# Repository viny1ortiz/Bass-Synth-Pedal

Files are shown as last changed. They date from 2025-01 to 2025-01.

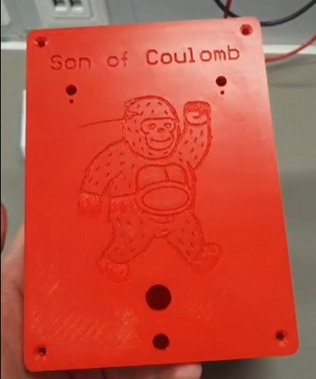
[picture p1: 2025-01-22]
3dprint/thumbnail.png

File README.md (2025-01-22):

# Son Of Coulomb - The Bass-Guitar Synthesizer Pedal

By: Vinicius Ourcilleon Ortiz and Gilberto Guerrero Carrillo  
**Rhine-Waal University of Applied Sciences**

A budget-friendly bass synthesizer pedal with square and triangle wave generation, designed and built for a university project. The objective of this project is to design and build a bass synthesizer pedal within a 20-euro budget. This budgetary constraint was not chosen out of necessity but as a deliberate design decision to limit the project's complexity and emphasize resourceful engineering.

The resulting pedal, named Son of Coulomb, processes the sinusoidal input signal from a bass guitar and offers several unique features. A dedicated switch allows the user to transform the input signal into either a triangular or square waveform. Another switch enables frequency multiplication, offering the option to shift the output one or two octaves higher (frequency multiplied by 2x or 4x).

The PCB design includes exposed pins for a microcontroller, allowing users to develop and upload custom effects. By connecting the microcontroller via jumpers, you can replace the default effect, which shifts the input signal one or two octaves up, with any custom effect of your choice through programming. This feature enhances the pedal's versatility and adaptability for creative experimentation.

Additionally, the pedal includes a 3PDT true bypass functionality, providing the user with seamless control to toggle between the unprocessed bass sound and the synthesized effect. This combination of simplicity, functionality, and cost-efficiency makes the Son of Coulomb an excellent showcase of analog signal processing and creative circuit design.

# How It Works: Flow Overview

To provide a clear understanding of the pedal's operation, the following workflow diagram outlines the core processes involved. This simple representation breaks down the system into distinct functional blocks, offering an intuitive overview of how the components interact. Below the diagram, each block is explained in detail to highlight its role within the system. Let’s explore each block step by step to understand how the Son of Coulomb transforms the input signal into the synthesized effect.



**Pre-Amplifier:** Before connecting the bass signal directly to the microcontroller, the signal must be amplified and offset to ensure compatibility with the microcontroller's input voltage range of 0 to 3.3V. Since the bass signal typically ranges between -100 mV and 100 mV, it is first offset to 1.65V (the midpoint of the microcontroller's input range) and then amplified to bring the signal within the acceptable voltage levels for accurate processing.

**MCU:** Within the microcontroller, the input signal is processed to extract its frequency. This frequency is then used to generate a PWM signal on two separate output pins, with the frequency scaled by a factor of 2 or 4, depending on the selected mode.

**SW1:** This switch simply selects whether the input frequency is multiplied by a factor of 2 or 4.

**Triangle Generator:** As the name suggests, the incoming signal from the microcontroller is converted from a square wave to a triangular wave using an integrator op-amp configuration.

**SW2:** This switch simply selects either a square or triangle wave, and its output goes directly to the effect output.

**Effect Bypass:** The effect bypass block, controlled by a 3PDT switch, determines whether the effect is active or bypassed. When the effect is enabled, the LED turns on, and the bass-guitar signal passes through the effect circuit. If the effect is bypassed, the signal is routed directly to the output jack, as depicted in the diagram.

**More details of the circuit can be seen in the "schematic" folder!**

# Demonstration

IMAGE ALT TEXT HERE (https://www.youtube.com/watch?v=soLUF7D458c)

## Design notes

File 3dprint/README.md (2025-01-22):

# Enclosure

This is the 3D CAD model of my enclosure, designed by my talented friend, mechanical engineer Vinod Seluam. It features four M4 screw threads and a reinforced structure to ensure durability, as the material will need to withstand foot pressure to activate the 3PDT foot-stomp switch. The printing process took approximately 12 hours. A big thank you to Vinod for his outstanding work on this design.




# Final Result

Watch "Pedal.mp4"!

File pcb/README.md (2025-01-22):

# Top Layer



# Bottom Layer



# Final Result



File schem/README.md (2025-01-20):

# Schematic

This schematic represents the complete design of the project. It outlines all key subcircuits that contribute to its functionality. We will now analyze each subcircuit in detail to understand their roles and operation.



# Power Supply


This is the power supply stage, designed to provide stable voltages for the circuit. The LM317 voltage regulator (IC1) is configured to generate a 3.3V output using resistors R7 and R1, with capacitor C3 providing additional stability. The input to the regulator is filtered by capacitor C5 to reduce noise. Additionally, a bias voltage is generated using a resistor divider network (R2 and R8), providing an offset of approximately 1.55V. This bias voltage is further stabilized by capacitor C4, ensuring a clean reference for subsequent stages in the circuit.

# Amplifier with Offset


This is the amplifier stage, primarily responsible for processing the signal before it is sent to the MCU. Resistor R17 provides high input impedance to preserve the signal integrity from the bass. The bias voltage, derived from the previously discussed power supply stage, offsets the signal by approximately 1.55V. The signal then passes through the voltage follower implemented with U1A and is subsequently amplified with a gain of approximately K=5.6 in U1B. The amplified output from U1B is connected directly to the MCU for further processing.

# MCU - STM32F103C8T6


This is the MCU stage, centered around the STM32F103C8T6 microcontroller, which handles signal processing and wave generation. The crystal oscillator (Y1) and its accompanying capacitors (C7 and C8) provide an 8 MHz clock for precise operation. The NRST pin is connected to a reset circuit, comprising a pull-up resistor (R3), a decoupling capacitor (C11), and a push-button (SW4) for manual resets.

For boot mode selection, the BOOT pin is configured using SW5 and pull-down resistor R15. The programming interface is accessible via J4, which connects the SWDIO and SWCLK lines for debugging and firmware uploads. Power stability is ensured with decoupling capacitors close to the MCU power pins, while pull-up resistor R4 supports proper initialization of the SWDIO line. Together, this stage forms the control hub of the system.

# Triangle Wave & Wave Selection


This is the triangle wave generator and wave selection stage. The input signal is chosen using the SPDT switch SW1, which selects between FX1 (2x frequency multiplier) and FX2 (4x frequency multiplier), sending the selected signal to the square wave output (SQR_OUT). The square wave is processed by a resistor-capacitor network (R5, R6, and C1), that basically removes the DC component of the signal so it can be fed into the integrator circuit implemented with U2A (LM358), which generates a triangle wave.

The SPDT switch SW2 allows selection between the square wave and triangle wave output. The chosen waveform is buffered by U2B, ensuring proper drive strength and signal integrity. The final output, labeled as 'Effect_out,' is conditioned by a resistor network (R9, R10) which decreases the amplitude of it to 10%, and decoupling capacitor C6 for stability and signal shaping. This stage provides the flexibility to toggle between waveforms.

# Effect Toggle - 3PDT


This is the toggling effect stage, which determines whether the signal bypasses the effect or passes through it. When the effect is activated, the LED illuminates, the input jack is connected to the effect input, and the effect output is routed to the output jack.

When toggled off, the LED turns off, the effect input is grounded to discharge any capacitors, and the input and output jacks are directly connected, bypassing the effect entirely and routing the signal straight to the amplifier.

# MCU Pin Headers


In this section, the MCU pins are directly routed to headers, enabling the use of the circuit as a versatile 'Pedal Effect' development board. This design allows users to create custom effects by programming the MCU and connecting the desired pins to the board for their specific effects. The SPDT switch (SW1) facilitates toggling between two effects, allowing up to two effects to be used simultaneously with seamless switching.

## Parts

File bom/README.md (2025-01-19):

The budget of this project was €20, however, we surpassed it a bit by €3.19

bom

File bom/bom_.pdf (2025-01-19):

Qty | Value | Description | Designator | Manufacturer | Manufacturer Part Number | Supplier | Supplier Part Number | Unit Cost | Cost
5 | 0.1u | Capacitor | C1, C3, C5, C10, C11 | Kyocera AVX | KAF21KR72A104KL | Mouser | 581-KAF21KR72A104KL | 0.16 € | 0.81 €
2 | 10u | Capacitor | C2, C6 | TDK | CGA3EDX7T1A106M080AU | Mouser | 810-CGA3EDX7T1A106M0 | 0.47 € | 0.93 €
1 | 47u | Capacitor | C4 | Nichicon | GXC1H470MCQ1GS | Mouser | 647-GXC1H470MCQ1GS | 1.11 € | 1.11 €
2 | 22p | Capacitor | C7, C8 | Kyocera AVX | 06036A220JAT2A | Mouser | 581-06036A220JAT2A | 0.10 € | 0.19 €
1 | 4.7u | Capacitor | C9 | Kyocera AVX | KAF21KR72A104KL | Mouser | 581-CM05X5R475M16AH | 0.21 € | 0.21 €
1 | Red LED | LED | DS1 | Cree LED | CMP-007-00007-2 | Mouser | 941-C566CRFECV0W0BB2 | 0.23 € | 0.23 €
1 | LM317DCY | IC | IC1 | Texas Instruments | LM317DCY | Mouser | 595-LM317DCY | 1.11 € | 1.11 €
1 | stm32f103c8t6 | MCU | IC2 | STMicroelectronics | stm32f103c8t6 | Reichelt | STM32 F103C8T6 | 1.60 € | 1.60 €
3 | Terminal Block - Jack in | Terminal Block | J1, J2, J3 | Same Sky | TB003-500-P02BE | Mouser | 490-TB003-500-P02BE | 0.46 € | 1.37 €
2 | 1.2k | Resistor | R1, R14 | Panasonic | ERJ-UP3F1201V | Mouser | 667-ERJ-UP3F1201V | 0.22 € | 0.44 €
4 | 47k | Resistor | R2, R6, R8, R11 | Panasonic | CR0603-JW-473ELF | Mouser | 652-CR0603-JW-473ELF | 0.10 € | 0.38 €
4 | 10k | Resistor | R3, R4, R9, R15 | ROHM Semiconductor | ESR03EZPJ103 | Mouser | 755-ESR03EZPJ103 | 0.11 € | 0.46 €
2 | 6.8k | Resistor | R5, R13 | Panasonic | ERJ-S03F6801V | Mouser | 667-ERJ-S03F6801V | 0.19 € | 0.38 €
1 | 1.8k | Resistor | R7 | Panasonic | ERA-6ARB182V | Mouser | 667-ERA-6ARB182V | 0.66 € | 0.66 €
2 | 1k | Resistor | R10, R16 | Panasonic | ERJ-P03F1001V | Mouser | 667-ERJ-P03F1001V | 0.16 € | 0.32 €
1 | 220 | Resistor | R12 | KOA Speer | RK73B1JTTDD221J | Mouser | 660-RK73B1JTTDD221J | 0.10 € | 0.10 €
2 | 1M | Resistor | R17, R18 | Vishay Draloric | RCV25121M00JNEG | Mouser | 71-RCV25121M00JNEG | 0.82 € | 1.63 €
2 | SPDT Switch | Switch | SW1, SW2 | Adafruit | 3221 | Mouser | 485-3221 | 0.90 € | 1.81 €
1 | 3PDT Switch | Switch | SW3 | E-Switch | FS57003PLT2B2M2QE | Mouser | 612-FS573PLT2B2M1QE | 7.59 € | 7.59 €
1 | Push Button (RESET) | Switch | SW4 | Apem | PHAP3344BR | Mouser | 642-PHAP3344BR | 0.42 € | 0.42 €
1 | Push Button (BOOT) | Switch | SW5 | Apem | PHAP3344BR | Mouser | 642-PHAP3344BR | 0.42 € | 0.42 €
2 | LM358DR | Dual Operational Amplifier | U1, U2 | Texas Instruments | LM358DR | Mouser | 595-LM358DR | 0.39 € | 0.78 €
1 | 8MHz | Crystal Oscillator | Y1 | Fox / Abracon | FOXSDLF_080-20 | Mouser | 559-FOXSD080-20-LF | 0.25 € | 0.25 €
| | | | | | | | Total Cost | 23.19 €

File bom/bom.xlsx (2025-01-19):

Qty |  | Value | Description | Designator | Manufacturer | Manufacturer Part Number | Supplier | Supplier Part Number | Unit Cost | Cost
5 | x | 0.1u | Capacitor | C1, C3, C5, C10, C11 | Kyocera AVX | KAF21KR72A104KL | Mouser | 581-KAF21KR72A104KL | 0.16 € | 0.81 €
2 | x | 10u | Capacitor | C2, C6 | TDK | CGA3EDX7T1A106M080AU | Mouser | 810-CGA3EDX7T1A106M0 | 0.47 € | 0.93 €
1 | x | 47u | Capacitor | C4 | Nichicon | GXC1H470MCQ1GS | Mouser | 647-GXC1H470MCQ1GS | 1.11 € | 1.11 €
2 | x | 22p | Capacitor | C7, C8 | Kyocera AVX | 06036A220JAT2A | Mouser | 581-06036A220JAT2A | 0.10 € | 0.19 €
1 | x | 4.7u | Capacitor | C9 | Kyocera AVX | KAF21KR72A104KL | Mouser | 581-CM05X5R475M16AH | 0.21 € | 0.21 €
1 |  | Red LED | LED | DS1 | Cree LED | CMP-007-00007-2 | Mouser | 941-C566CRFECV0W0BB2 | 0.23 € | 0.23 €
1 | x | LM317DCY | IC | IC1 | Texas Instruments | LM317DCY | Mouser | 595-LM317DCY | 1.11 € | 1.11 €
1 |  | stm32f103c8t6 | MCU | IC2 | STMicroelectronics | stm32f103c8t6 | Reichelt | STM32 F103C8T6 | 1.60 € | 1.60 €
3 |  | Terminal Block - Jack in | Terminal Block | J1, J2, J3 | Same Sky | TB003-500-P02BE | Mouser | 490-TB003-500-P02BE | 0.46 € | 1.37 €
2 | x | 1.2k | Resistor | R1, R14 | Panasonic | ERJ-UP3F1201V | Mouser | 667-ERJ-UP3F1201V | 0.22 € | 0.44 €
4 | x | 47k | Resistor | R2, R6, R8, R11 | Panasonic | CR0603-JW-473ELF | Mouser | 652-CR0603-JW-473ELF | 0.10 € | 0.38 €
4 | x | 10k | Resistor | R3, R4, R9, R15 | ROHM Semiconductor | ESR03EZPJ103 | Mouser | 755-ESR03EZPJ103 | 0.11 € | 0.46 €
2 | x | 6.8k | Resistor | R5, R13 | Panasonic | ERJ-S03F6801V | Mouser | 667-ERJ-S03F6801V | 0.19 € | 0.38 €
1 | x | 1.8k | Resistor | R7 | Panasonic | ERA-6ARB182V | Mouser | 667-ERA-6ARB182V | 0.66 € | 0.66 €
2 | x | 1k | Resistor | R10, R16 | Panasonic | ERJ-P03F1001V | Mouser | 667-ERJ-P03F1001V | 0.16 € | 0.32 €
1 | x | 220 | Resistor | R12 | KOA Speer | RK73B1JTTDD221J | Mouser | 660-RK73B1JTTDD221J | 0.10 € | 0.10 €
2 | x | 1M | Resistor | R17, R18 | Vishay Draloric | RCV25121M00JNEG | Mouser | 71-RCV25121M00JNEG | 0.82 € | 1.63 €
2 |  | SPDT Switch | Switch | SW1, SW2 | Adafruit | 3221 | Mouser | 485-3221 | 0.90 € | 1.81 €
1 |  | 3PDT Switch | Switch | SW3 | E-Switch | FS57003PLT2B2M2QE | Mouser | 612-FS573PLT2B2M1QE | 7.59 € | 7.59 €
1 |  | Push Button (RESET) | Switch | SW4 | Apem | PHAP3344BR | Mouser | 642-PHAP3344BR | 0.42 € | 0.42 €
1 |  | Push Button (BOOT) | Switch | SW5 | Apem | PHAP3344BR | Mouser | 642-PHAP3344BR | 0.42 € | 0.42 €
2 | x | LM358DR | Dual Operational Amplifier | U1, U2 | Texas Instruments | LM358DR | Mouser | 595-LM358DR | 0.39 € | 0.78 €
1 | x | 8MHz | Crystal Oscillator | Y1 | Fox / Abracon | FOXSDLF_080-20 | Mouser | 559-FOXSD080-20-LF | 0.25 € | 0.25 €
 |  |  |  |  |  |  |  |  | Total Cost | 23.19 €

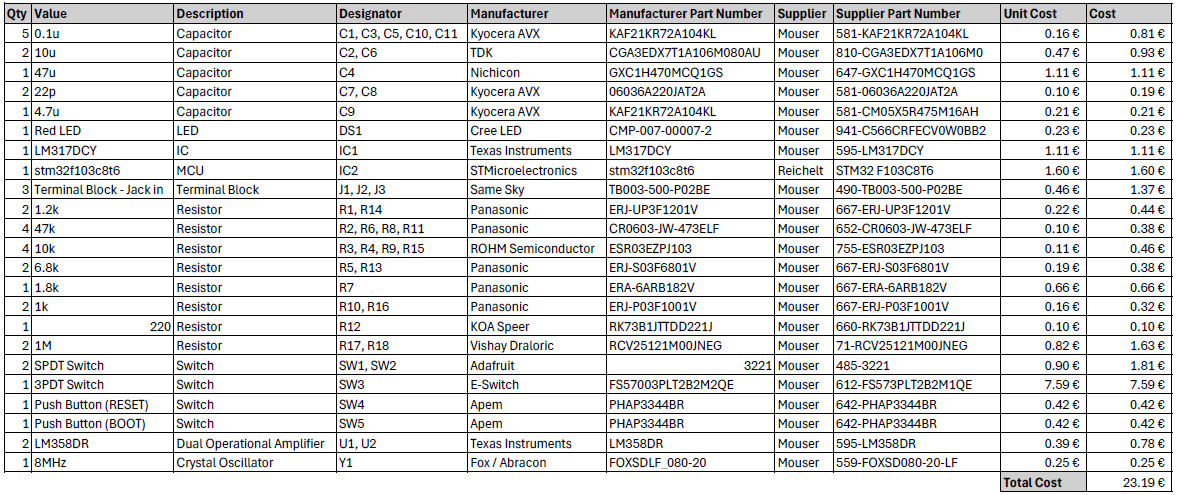
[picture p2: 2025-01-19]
bom/bom.png

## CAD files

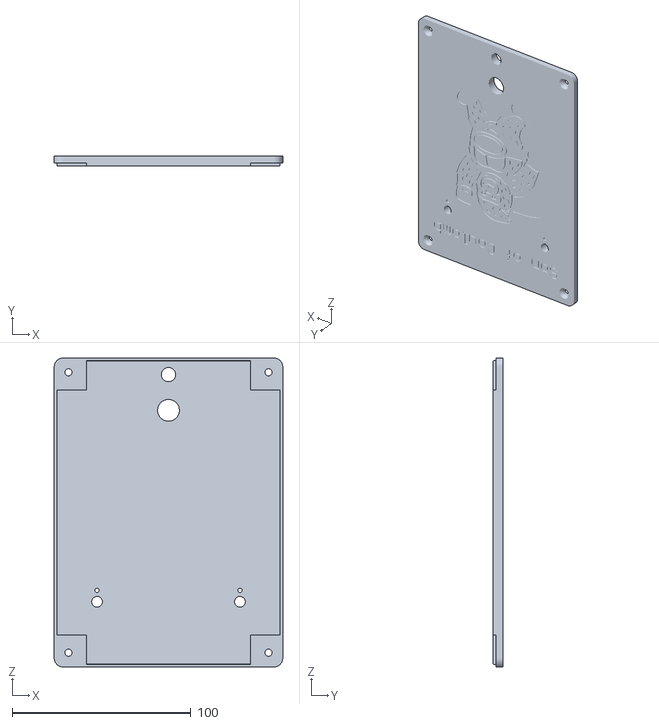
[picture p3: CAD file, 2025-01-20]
3dprint/Cover.STL
128.0 x 5.50 x 173.0

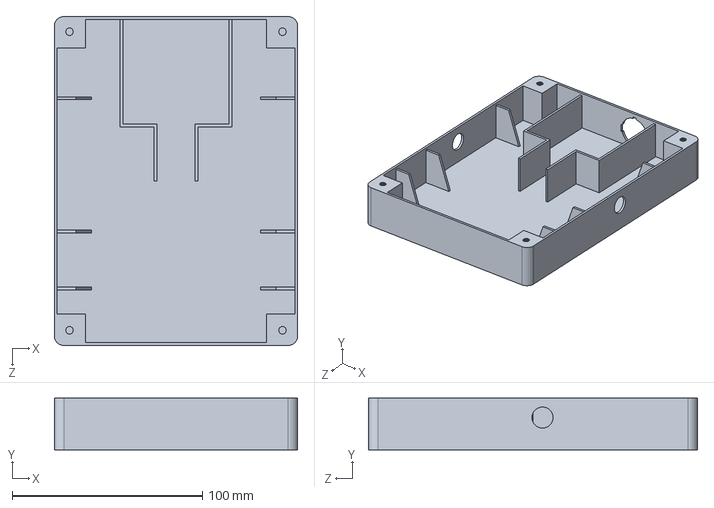
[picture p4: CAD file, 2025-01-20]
3dprint/Body.SLDPRT
128.0 x 27.2 x 173.0 mm

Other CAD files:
3dprint/Body.STL

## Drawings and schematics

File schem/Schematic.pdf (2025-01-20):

Power Supply | Triangle Wave Generator & Wave Selection

## Effect Toggle

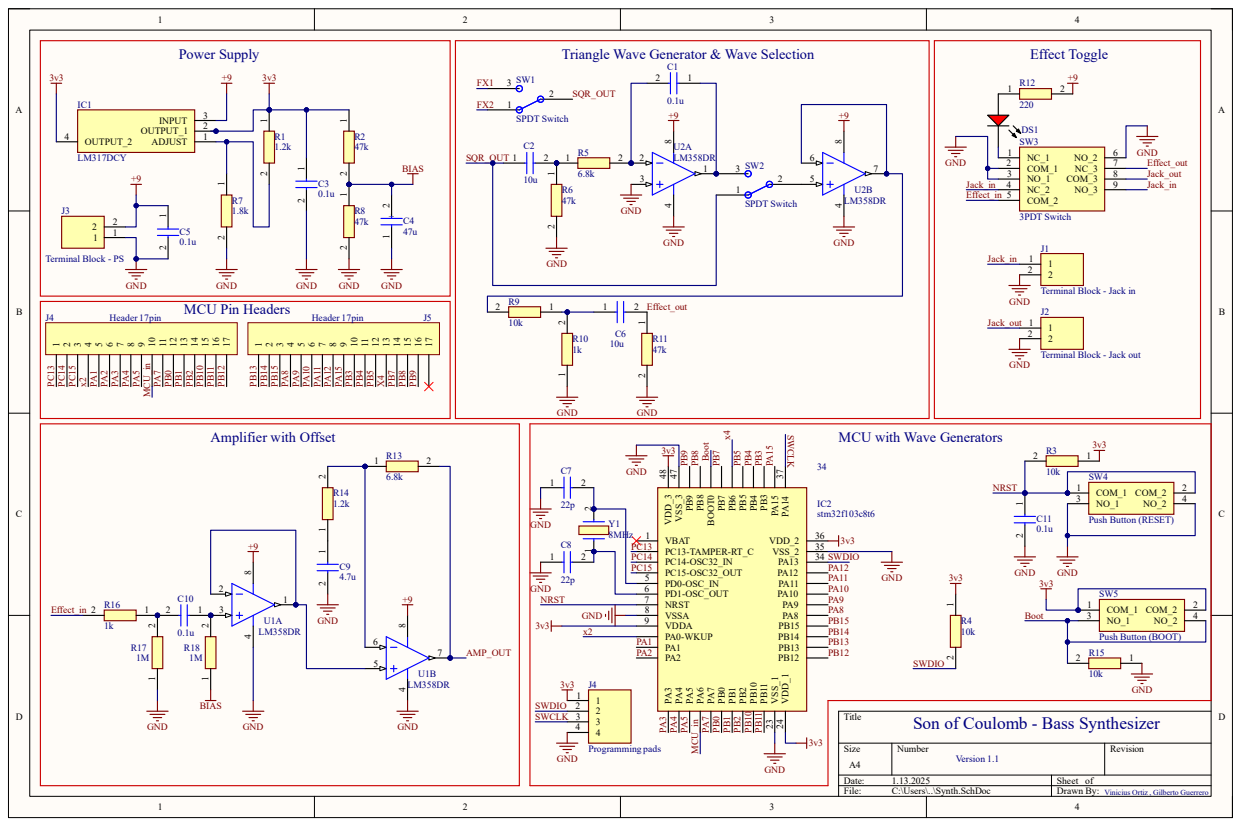
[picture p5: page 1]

Terminal Block - Jack out
GND

MCU with Wave Generators

Push Button (BOOT) Boot

PB12 VDD_3 48 VSS_3 47 PB⁹ PB⁸ BOOT⁰ PB⁷ PB⁶ PB⁵ PB⁴ PB³ PA¹⁵ PA¹⁴ ³⁷

PA2PA³ PA⁴ PA⁵ PA⁶ PA⁷ PB⁰ PB¹ PB² PB¹⁰ PB¹¹ VSS_1 23 VDD_1 24

Son of Coulomb - Bass Synthesizer

Vinicius Ortiz , Gilberto Guerrero

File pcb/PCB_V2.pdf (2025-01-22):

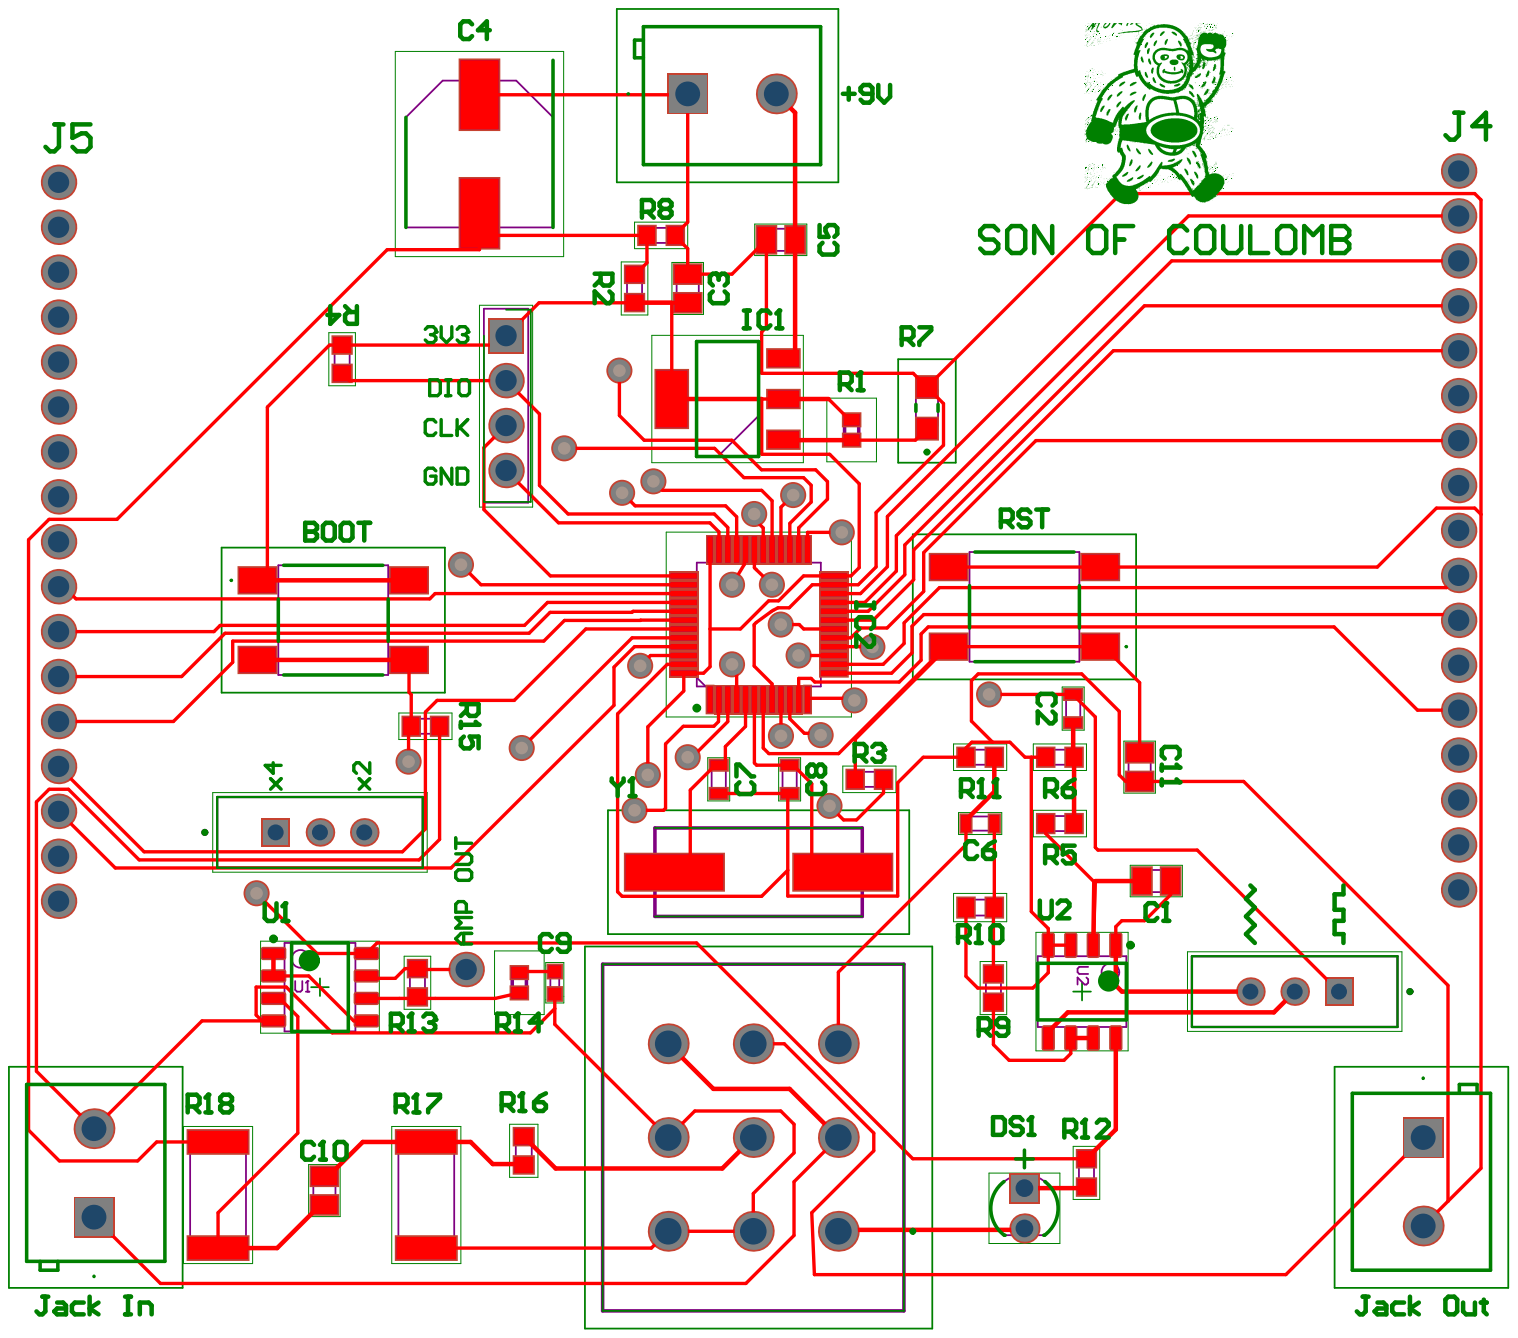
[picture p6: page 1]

# 11 PB44PA83 PB15 2 PB14 1 PB13 6 PA10 5PA99 PA15

# 11 PB44PA83 PB15 2 PB14 1 PB13 6 PA10 5PA99 PA15

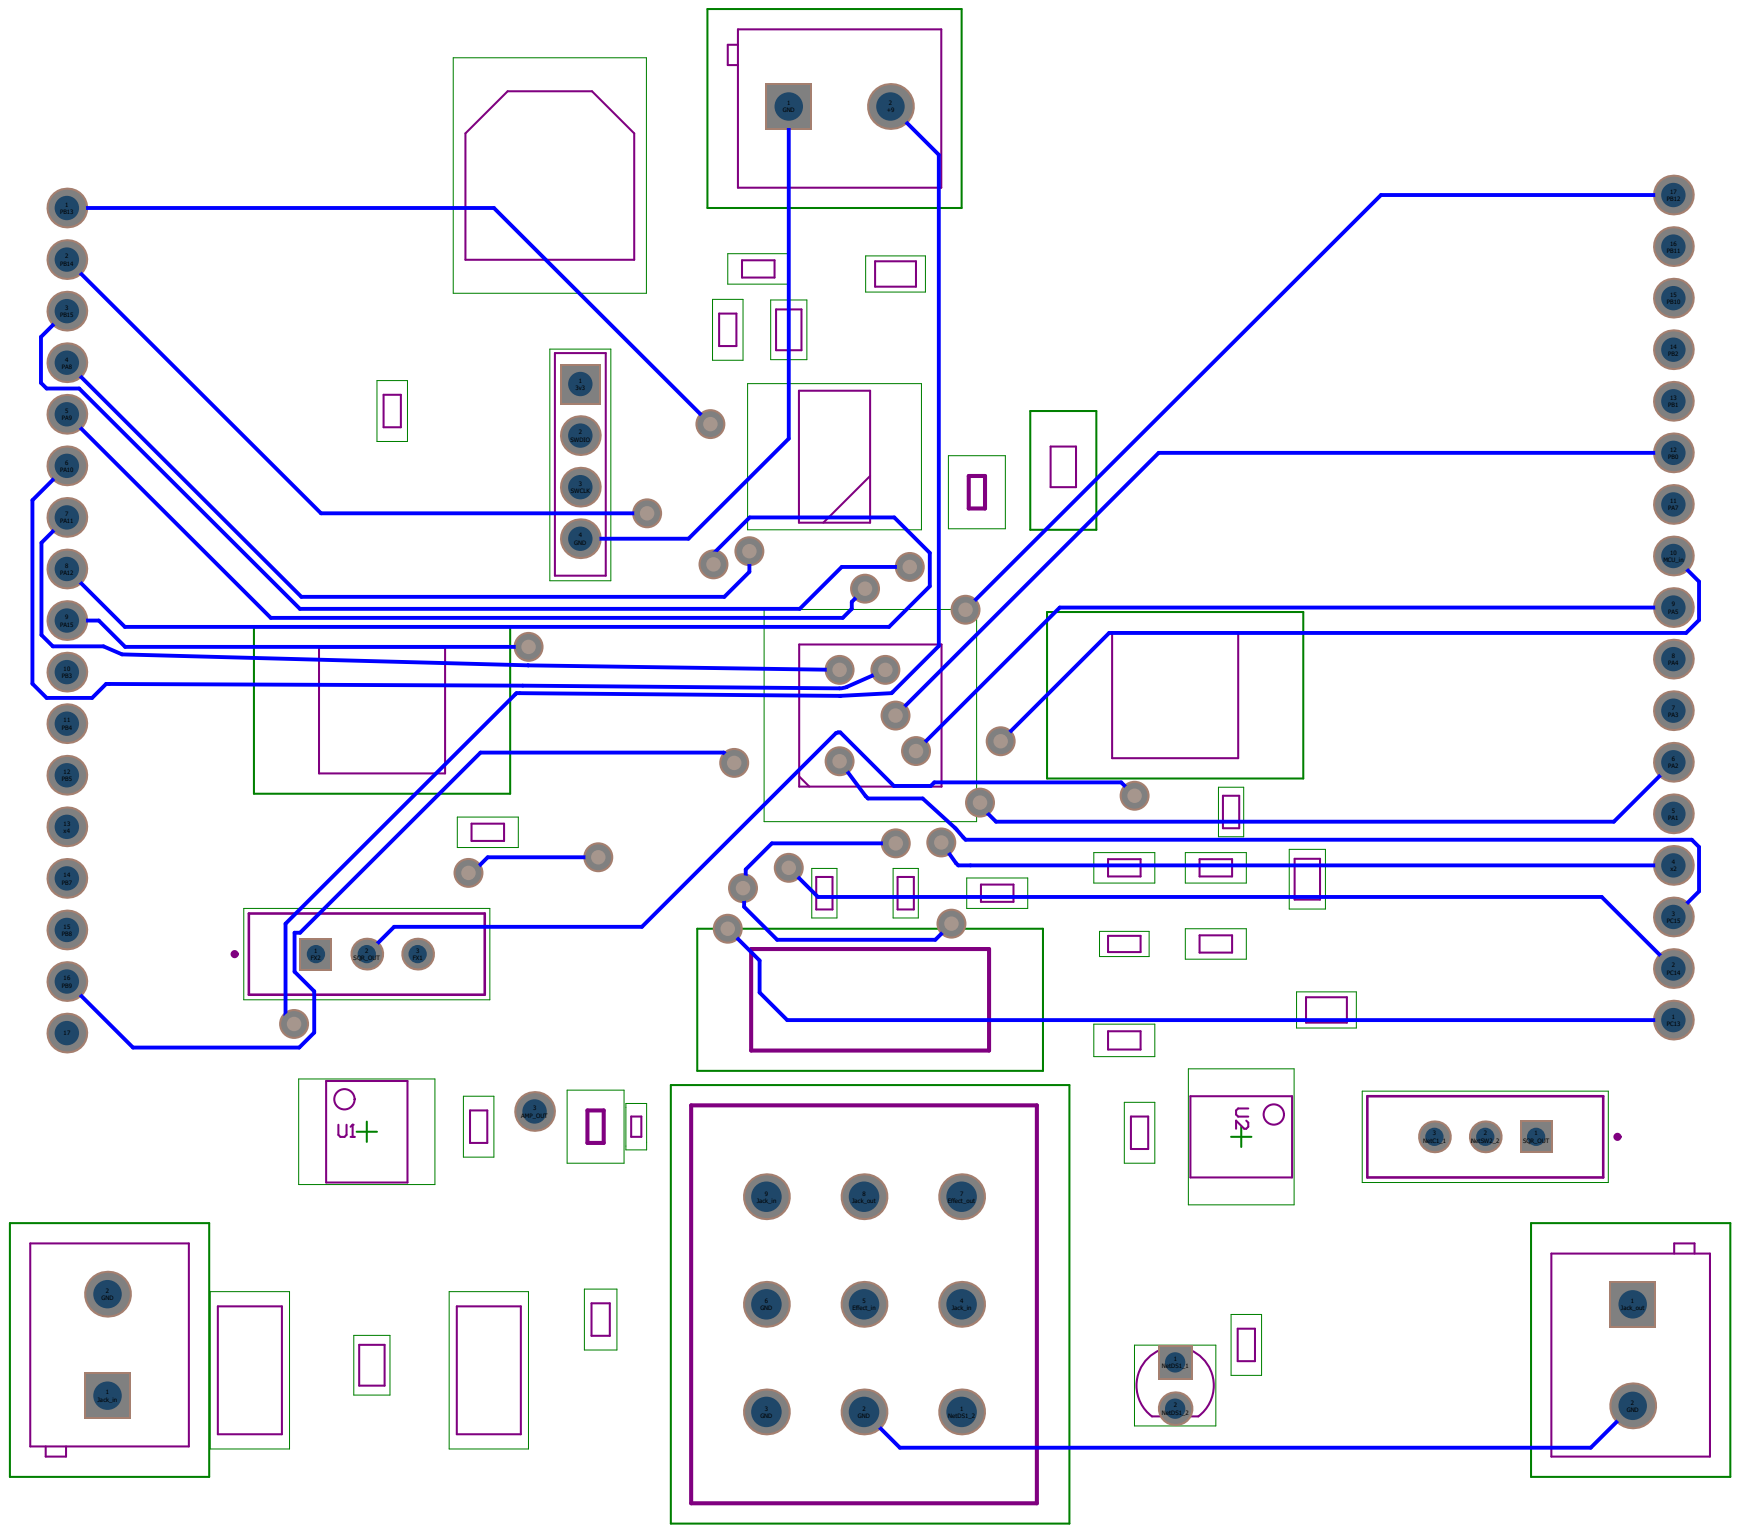
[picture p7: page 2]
2 GND 3 GND 1; Jack_in; 5 Effect_in 6 GND 2GND; Jack_out 3 AMP_OUT; 2 SQR_OUT; 3v32 SWDIO 3 SWCLK 4 GND; 1 GND; 1 NetDS1_2; 2 NetDS1_2; 2GND 1 NetDS1_1 4; Jack_out 7 Effect_out; 2 NetSW2_2; 1 SQR_OUT 3 NetC1_1; 10 MCU_in 2 GND 3 GND 1; 10 MCU_in

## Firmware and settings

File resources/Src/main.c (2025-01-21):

/*
 * bassSynthetizerCode.c
 *
 *  Created on: Nov 14, 2024
 *      Author: Gilberto Guerrero Carrillo
 *      		Vinicius Ortiz Ourcilleon
*/
#include <stdint.h>
#include "stm32f103c8t6.h"


volatile uint16_t frequency = 0;  // Measured frequency
volatile uint32_t value1 = 0, value2 = 0;
#define FILTER_SIZE 8
volatile uint16_t frequency_buffer[FILTER_SIZE] = {0};
volatile uint8_t index = 0;
volatile uint16_t avg_frequency = 0;
// Initialize GPIO for Input Capture (TIM3 on PA6)
void GPIO_Init_Input() {
    RCC->APB2ENR |= (1 << 2);  // Enable GPIOA clock
    GPIOA->CRL &= ~(0xF << 24);  // Clear PA6 configuration
    GPIOA->CRL |= (0x4 << 24);   // PA6 as input floating
}

// Initialize TIM3 for Input Capture on PA6
void TIM3_InputCapture_Init() {
    RCC->APB1ENR |= (1 << 1);  // Enable TIM3 clock

    TIM3->PSC = 10 - 1;  //  8MHz/9 timer clock
    TIM3->ARR = 0xFFFF;  // Max auto-reload value
    TIM3->CCMR1 |= (1 << 0);  // Capture input on TI1 (CC1S = 01)
    TIM3->CCER |= (1 << 0);   // Enable capture on CH1
    TIM3->DIER |= (1 << 1);   // Enable CC1 interrupt
    TIM3->CR1 |= (1 << 0);    // Enable TIM3 counter

    NVIC_EnableIRQ(TIM3_IRQn);  // Enable TIM3 interrupt
}

// Initialize GPIO for PWM Outputs
void GPIO_Init_Output() {
    RCC->APB2ENR |= (1 << 2);  // Enable GPIOA clock
    GPIOA->CRL &= ~(0xFF << 0);  // Clear PA0 and PA1 configuration
    GPIOA->CRL |= (0xB << 0);//   // PA0 and  as alternate function push-pull

    RCC->APB2ENR |= (1 << 3);	//Enable GPIOB clock
    GPIOB->CRL &= ~(0xF << 24);  // Clear PB6 configuration
    GPIOB->CRL |= (0xB << 24);   // Set PB6 to AF push-pull, 50 MHz output
}

// Initialize TIM2 for 2x Frequency PWM (PA0)
void TIM2_PWM_Init() {
    RCC->APB1ENR |= (1 << 0);  // Enable TIM2 clock
    TIM2->PSC =10 - 1;  // 8MHz/9 timer clock
    TIM2->ARR = 800 - 1;  // Default frequency
    TIM2->CCR1 = 400;  // 50% duty cycle

    TIM2->CCMR1 |= (6 << 4);  // PWM mode 1 on CH1
    TIM2->CCER |= (1 << 0);   // Enable CH1 output
    TIM2->CR1 |= (1 << 0);    // Enable TIM2 counter
    TIM2->CR1 |= (1<<7);
}

// Initialize TIM4 for 4x Frequency PWM (PA1)
void TIM4_PWM_Init() {
    RCC->APB1ENR |= (1 << 2);  // Enable TIM4 clock
    TIM4->PSC = 10 - 1;  // 8MHz/9  timer clock
    TIM4->ARR = 400 - 1;  // Default frequency
    TIM4->CCR1 = (TIM4->ARR + 1)/2;  // 50% duty cycle

    TIM4->CCMR1 &= ~(0xFF << 0);
    TIM4->CCMR1 |= (6 << 4);  // PWM mode 1 on CH1
    TIM4->CCER |= (1 << 0);   // Enable CH1 output
    TIM4->CR1 |=(1<<7);
    TIM4->CR1 |= (1 << 0);    // Enable TIM4 counter
}

// TIM3 Interrupt Handler for Frequency Measurement
void TIM3_IRQHandler() {
    if (TIM3->SR & (1 << 1)) {  // Check for capture flag
        TIM3->SR &= ~(1 << 1);  // Clear flag
        value2 = TIM3->CCR1;

        if (value2 > value1) {
            frequency = 1000000 / (value2 - value1);  // Calculate frequency
        } else {
            frequency = 0;  // Handle timer overflow
        }

        value1 = value2;  // Update last capture value
    }
}

// Update PWM Frequencies
void Update_PWM_Frequencies() {
	// Store frequency in buffer for averaging
	frequency_buffer[index] = frequency;
	index = (index + 1) % FILTER_SIZE;
	// Compute the average frequency
	uint32_t sum = 0;
	for (uint8_t i = 0; i < FILTER_SIZE; i++) {
       sum += frequency_buffer[i];
	}
	avg_frequency = sum / FILTER_SIZE;

    if (frequency > 20) {
        TIM2->ARR = (1000000 / ( 2*avg_frequency)) - 1;
        TIM2->CCR1 = (TIM2->ARR + 1) / 2;

        TIM4->ARR = (1000000 / (4 * avg_frequency
        		)) - 1;
        TIM4->CCR1 = (TIM4->ARR + 1) / 2;
    }else{
    	frequency=0;
    }
}
void RCC_Init() {
    // Enable HSE
    RCC->CR |= (1<<16);;  // Turn on HSE oscillator
    while ((RCC->CR & (1<<17)) == 0);  // Wait for HSE to be ready

    // Select HSE as the system clock
    RCC->CFGR |= (1 << 0);  // Set HSE as system clock
    while ((RCC->CFGR & (3 << 2)) != (1 << 2));
}
int main(void) {
	RCC_Init();
    GPIO_Init_Input();
    TIM3_InputCapture_Init();
    GPIO_Init_Output();
    TIM2_PWM_Init();
    TIM4_PWM_Init();

    while (1) {
        Update_PWM_Frequencies();
    }
}

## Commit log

2025-01-20 schematic added
2025-01-22 pcb layers
